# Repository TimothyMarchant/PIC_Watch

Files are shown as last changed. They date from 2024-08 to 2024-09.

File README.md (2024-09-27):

# PIC_Watch
A digital watch that tells the time and temperature.  It uses the PIC15225 microcontroller.  The screen is a 0.96 inch OLED (SSD1306).  
The purpose of this project was to make an actual embedded application because I was in need of a watch.  

Here are some pictures from start to finish.  

Breadboard prototype

prototype PCB

Finalized PCB with components soldered on
Without the screen (this is actually a different PCB than the other two pictures!)

Back side

With the screen


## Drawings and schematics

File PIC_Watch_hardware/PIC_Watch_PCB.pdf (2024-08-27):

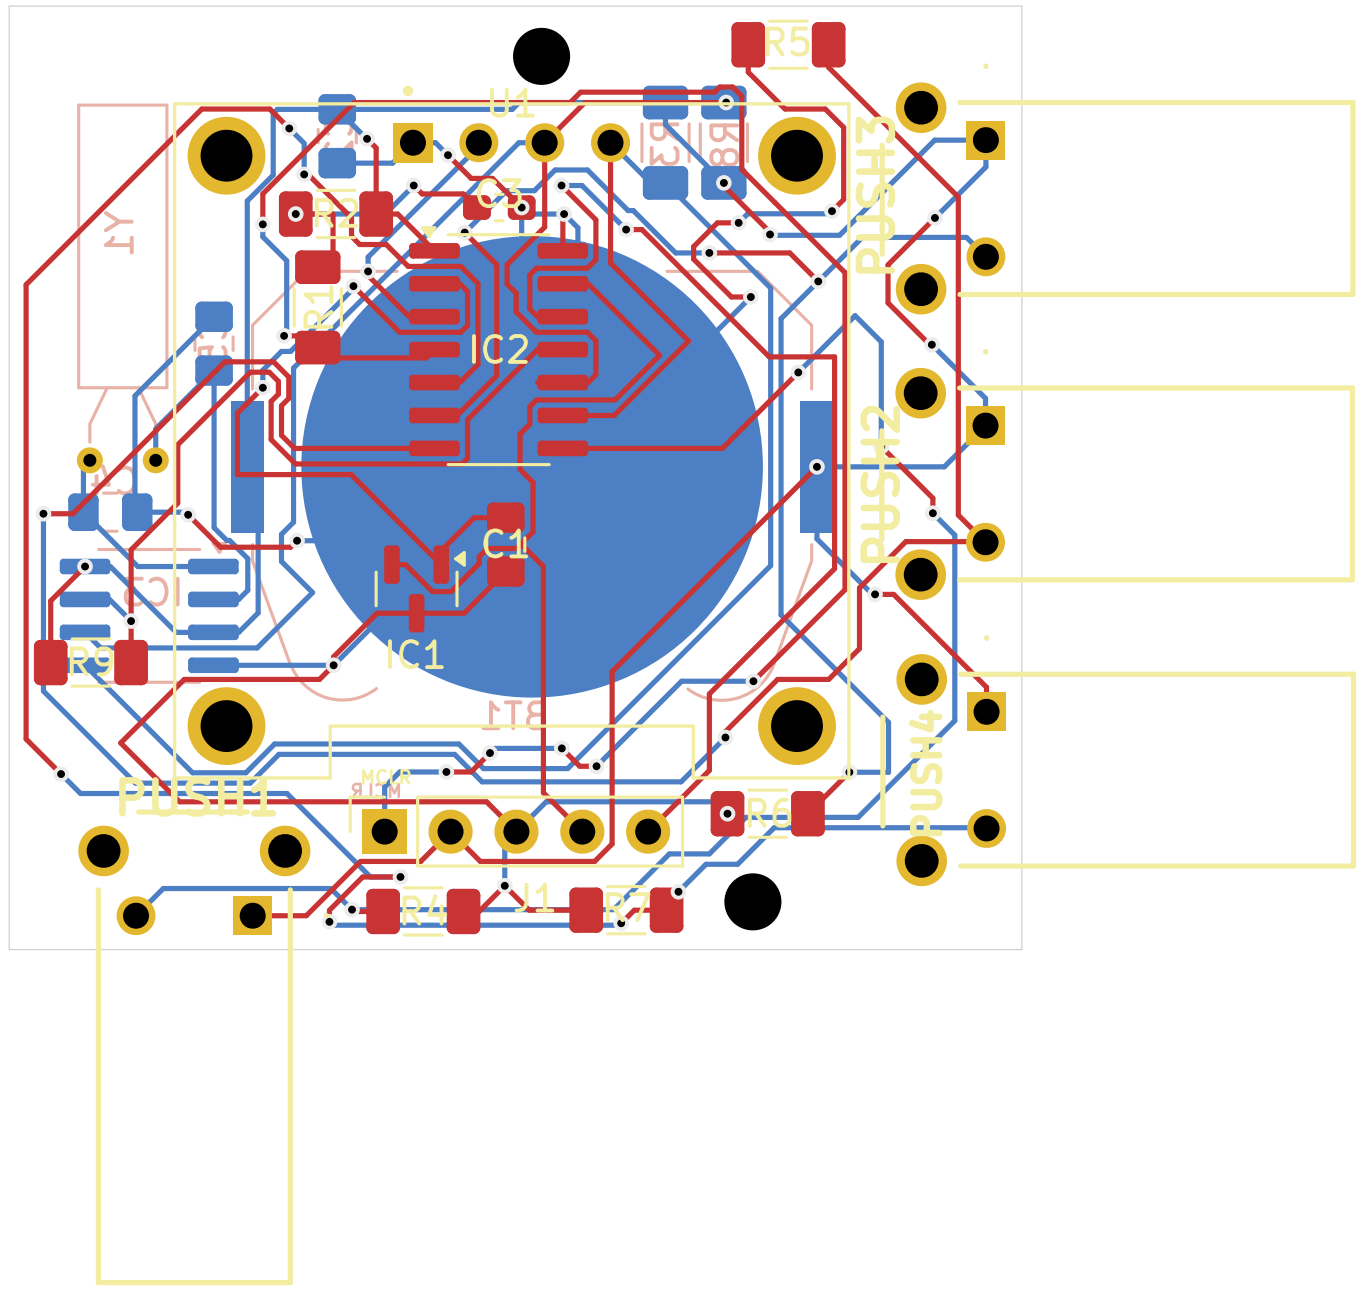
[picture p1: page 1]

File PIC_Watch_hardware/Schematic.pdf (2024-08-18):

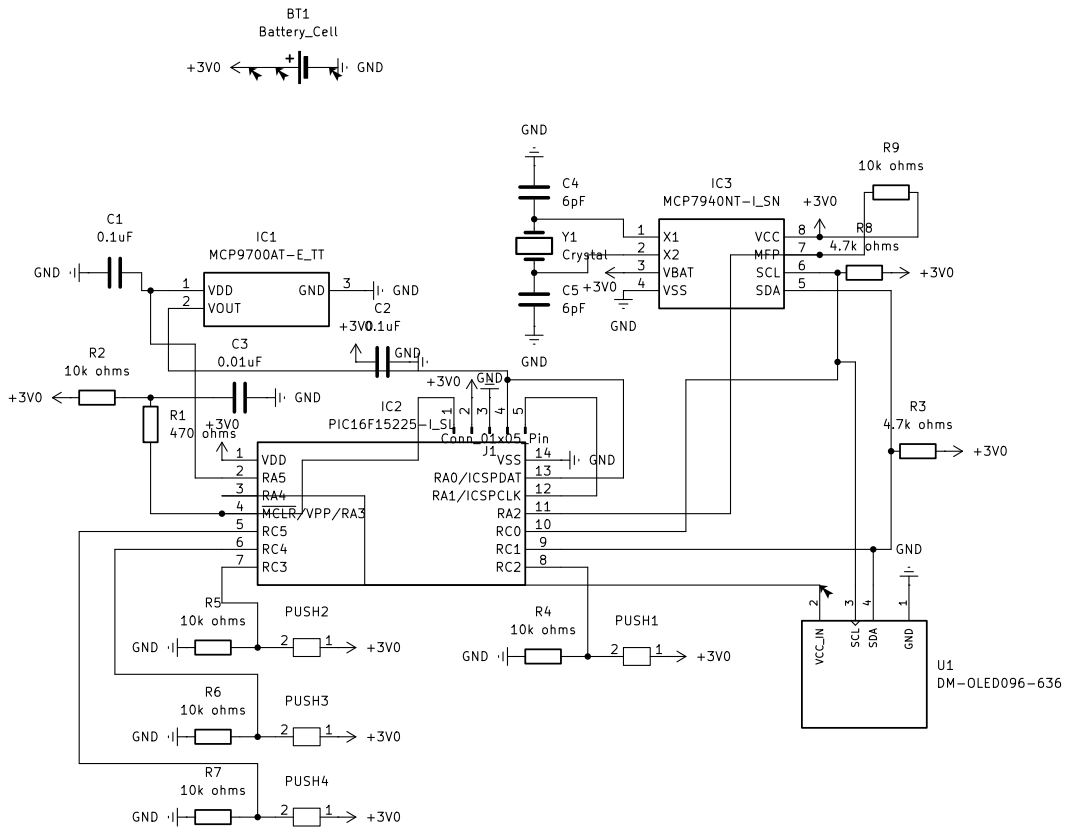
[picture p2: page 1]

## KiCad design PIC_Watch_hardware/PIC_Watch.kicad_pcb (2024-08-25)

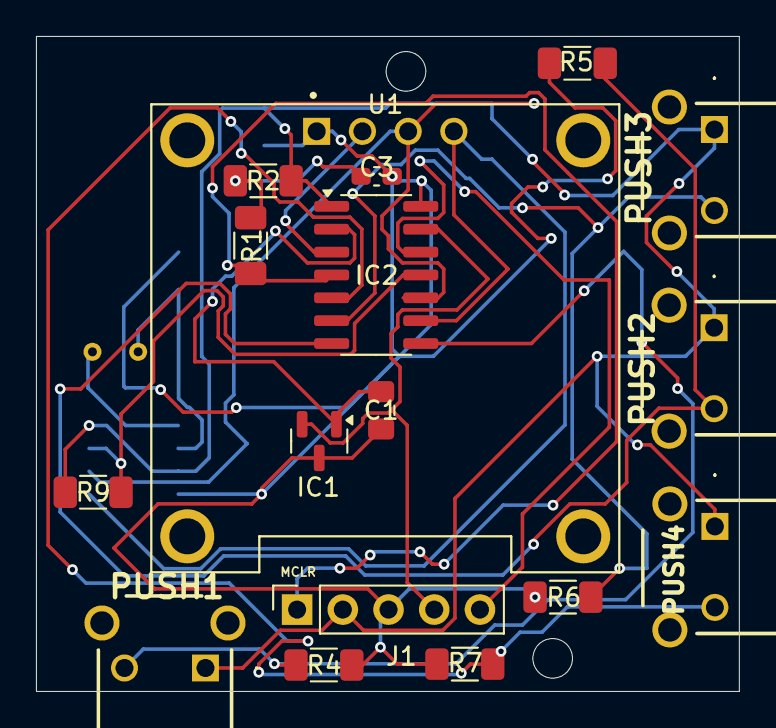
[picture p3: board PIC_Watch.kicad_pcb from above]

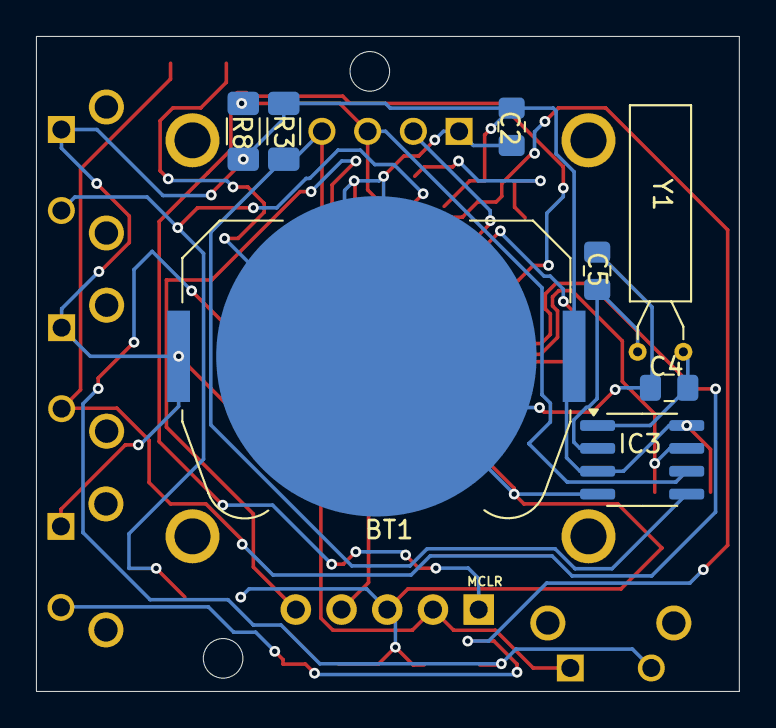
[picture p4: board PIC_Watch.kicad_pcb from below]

Board: 2 copper layers, 39.1 x 36.4 mm, 25 parts (8 on the bottom side), 17 nets.

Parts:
BT1: Battery_Cell; BatteryHolder_Keystone_3034_1x20mm
C1, C2: 0.1uF; C_0805_2012Metric_Pad1.18x1.45mm_HandSolder
C3: 0.01uF; C_0603_1608Metric_Pad1.08x0.95mm_HandSolder
C4, C5: 6pF; C_0805_2012Metric_Pad1.18x1.45mm_HandSolder
IC1: MCP9700AT-E_TT; SOT-23
IC2: PIC16F15225-I_SL; SOIC-14_3.9x8.7mm_P1.27mm
IC3: MCP7940NT-I_SN; SOIC-8_3.9x4.9mm_P1.27mm
J1: Conn_01x05_Pin; PinSocket_1x05_P2.54mm_Vertical
PUSH1, PUSH2, PUSH3, PUSH4: TS11674153BK160RAD
R1: 470 ohms; R_1206_3216Metric_Pad1.30x1.75mm_HandSolder
R2, R4, R5, R6, R7, R9: 10k ohms; R_1206_3216Metric_Pad1.30x1.75mm_HandSolder
R3, R8: 4.7k ohms; R_1206_3216Metric_Pad1.30x1.75mm_HandSolder
U1: DM-OLED096-636; MODULE_DM-OLED096-636
Y1: Crystal; Crystal_AT310_D3.0mm_L10.0mm_Horizontal

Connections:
+3V0: BT1.1 (+), C2.1, IC2.1 (VDD), IC3.3 (VBAT), IC3.8 (VCC), J1.2, PUSH1.1, PUSH2.1, PUSH3.1, PUSH4.1, R2.1, R3.2, R8.2, R9.2
GND: BT1.2 (-), C1.1, C2.2, C3.2, C4.2, C5.1, IC1.3 (GND), IC2.14 (VSS), IC3.4 (VSS), J1.3, R4.1, R5.1, R6.1, R7.1, U1.1 (GND)
unnamed: C3.1, R1.1, R2.2
unnamed: C1.2, IC1.1 (VDD), IC2.2 (RA5)
unnamed: IC1.2 (VOUT), IC2.13 (RA0/ICSPDAT), J1.4
unnamed: IC2.12 (RA1/ICSPCLK), J1.5
unnamed: IC2.11 (RA2), IC3.7 (MFP), R9.1
unnamed: IC2.3 (RA4), U1.2 (VCC_IN)
unnamed: IC2.10 (RC0), IC3.6 (SCL), R8.1, U1.3 (SCL)
unnamed: IC2.9 (RC1), IC3.5 (SDA), R3.1, U1.4 (SDA)
unnamed: IC2.8 (RC2), PUSH1.2, R4.2
unnamed: IC2.7 (RC3), PUSH2.2, R5.2
unnamed: IC2.6 (RC4), PUSH3.2, R6.2
unnamed: IC2.5 (RC5), PUSH4.2, R7.2
unnamed: IC2.4 (~MCLR/VPP/RA3), J1.1, R1.2
unnamed: C4.1, IC3.1 (X1), Y1.1
unnamed: C5.2, IC3.2 (X2), Y1.2

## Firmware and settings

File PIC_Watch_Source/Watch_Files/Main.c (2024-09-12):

#include "CONFIG.h"
#include "I2C_Drivers_PIC16F15225.h"
#include "SSD1306_Drivers.h"
#include "MCP9700_Drivers.h"
#include "MCP7940_Drivers.h"
/* This project uses the MCP7940N RTC, SSD1306, and the MCP9700 analog temperature sensor
 * This microcontroller was picked for several reasons
 * 1st, I had these in my house already and seemed to be big enough to do the job.
 * 2nd it's small enough for a <1.5 inch PCB (need it to be smaller than this more than likely; the PCB that is).
 * 
 */
#ifndef _XTAL_FREQ
#define _XTAL_FREQ 32000000
#endif
#define Button1 PORTCbits.RC2
#define Button2 PORTCbits.RC3
#define Button3 PORTCbits.RC4
#define Button4 PORTCbits.RC5
#define INTDATA 0xFF
#define PORTCButtons 0b00111100
#define OLED_POWER LATA4
void SendNumber(unsigned int);
void SendByte(unsigned char);
void HandleButton(unsigned char);
void EnableInterrupts(void);
void IncrementTimer1cnt(void);
unsigned char GetTimer1cnt(void);
unsigned int timer0cnt = 0;
unsigned char data = 0;
_Bool DeepSleep = 0;
_Bool IsPressed = 0;
_Bool NeedToUpdateTime=0;
void GotoSleep(void);
void DisplayTime(void);
void DisplayState(void);
void UpdateTimeArray(void);
void UpdateDateArray(void);
void UpdateYearArray(void);
void __interrupt() ISR(void) {
    //I2C recovery
    if (TMR1IF) {
        TMR1ON=0;
        IncrementTimer1cnt();
        TMR1IF=0;
        //timeout has clearly gone on too long restart the device after sending 9 clock pulses.
        if (GetTimer1cnt()==0xFF){
            ForceReset();
        }
        TMR1=0;
        TMR1ON=1;
    }
    //wakeup device.
    if (IOCCF>0) {
        //for debouncing
        __delay_ms(50);
        //get inputs from RC2-RC5 only.
        data = (PORTC & PORTCButtons)>>2;
        IOCCF = 0;
        IOCIF = 0;
        NeedToUpdateTime=0;
    }
    //alarm interrupt
    if (IOCAF>0){
        NeedToUpdateTime=1;
        //we need not update anything here, as the alarm pin will not change states until we modify the internal registers of the RTC.
        //The compiler gave a warning when we call such methods saying possible stack overflow.
        IOCIF=0;
        IOCAF=0;
    }
}
//this is for other files so that it can be changed elsewhere.
void GotoSleep(void){
    //
    DeepSleep=1;
    //do some other things.
}
void main(void) {
    TRISA = 0x00;
    LATA = 0x00;
    TRISA0=1;
    ANSELA=0x01;
    TRISA2=1;
    LATC = 0x00;
    //RC2-RC5 are all inputs.
    TRISC = 0xFF;
    ANSELC = 0x00;
    WPUC = 0x00;
    WPUA=0x00;
    OLED_POWER=1;
    Temp_Init(&LATA, 5);
    EnableInterrupts();
    I2C_Init();
    __delay_ms(50);
    init_OLED();
    MCP7940_Init();
    while (1) {
        //don't turn off the screen immediately wait some time then turn it off.
        HandleButton(data);
        if (DeepSleep) {
            DisplayTurnOff();
            //turn off alarm0 no interrupts are made in deep sleep.
            TurnOffInterrupt();
            //wait a little before just turning off the screen.
            __delay_ms(1);
            ClearAlarm0Interrupt();
            OLED_POWER=0;
            TMR1IE=0;
            data=0x00;
        }
        SLEEP();
        //We need this here instead of the ISR to avoid stack overflow.  The stack can only go 15 deep according to the datasheet (the compiler made a warning about it).
        
        //turn the screen back on.
        if (DeepSleep&&data!=0x00) {
            OLED_POWER=1;
            //wait some time before sending any commands.  the datasheet of the SSD1306 has the timing diagrams lasting a few microseconds, but I rather just wait longer
            //to avoid any problems.
            __delay_ms(25);
            init_OLED();
            //prevents the screen from having garbage shown.
            DisplayTurnOff();
            DeepSleep = 0;
        }
        if (NeedToUpdateTime){
            //update alarm time.
            updatealarm0();
            data=INTDATA;
            DeepSleep=0;
            NeedToUpdateTime=0;
        }
    }
}

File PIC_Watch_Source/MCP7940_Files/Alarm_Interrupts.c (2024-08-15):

//This file is special that it allows alarm0 to be configured to go off every minute to indicate that a new minute has past.
//It has no other function.  This makes it so that the microcontroller need not poll the RTC.
#include "I2C_Drivers_PIC16F15225.h"
#include "RTC_Addresses.h"
//starting values
//nonbinary time
unsigned char alarm0minutes[2]={0,0};
//these are the default control bytes for both alarms
//Alarm0 is set to go off on the matching of minutes.
#define Alarm0Control 0x10
//need this so that the methods below can call it.
void StartTransmission(unsigned char);
void ClearAlarm0Interrupt(void);
void updatealarm1(void);
//default options for control register
#define defaultcontrol 0x10
void updatealarmminutes(void){
    alarm0minutes[1]++;
    if (alarm0minutes[1]<10){
        return;
    }
    alarm0minutes[0]++;
    alarm0minutes[1]=0;
    if (alarm0minutes[0]==6){
        alarm0minutes[0]=0;
    }
}
void Init_Alarm0(void){
    StartTransmission(ALM0WKDay);
    I2C_Write(Alarm0Control);
    I2C_Restart();
    I2C_Write(RTC_Add);
    I2C_Write(CONTROL);
    I2C_Write(defaultcontrol);
    I2C_Stop();

}
void updatealarm0(void){
    //move memory pointer to minutes register
    StartTransmission(RTCMin);
    I2C_Restart();
    //read the minutes register.
    I2C_Write(RTC_Add|0x01);
    unsigned char temp=I2C_Read();
    NACK();
    //convert the binary time into something more useful.
    alarm0minutes[0]=(temp&0x70)>>4;
    alarm0minutes[1]=temp&0x0F;
    updatealarmminutes();
    unsigned char BINAlarmTime=(alarm0minutes[0]<<4)|alarm0minutes[1];
    I2C_Restart();
    I2C_Write(RTC_Add);
    I2C_Write(ALM0Min);
    I2C_Write(BINAlarmTime);
    //write to hours register to get to weekday register which contains the interrupt flag.
    //it's faster to write one byte here than restart the bus to get to the other register.
    I2C_Write(0x00);
    //update interrupt flag.
    I2C_Write(Alarm0Control);
    I2C_Stop();
}
void ClearAlarm0Interrupt(void){
    StartTransmission(ALM0WKDay);
    I2C_Write(Alarm0Control);
    I2C_Stop();
}
void TurnOffInterrupt(void){
    StartTransmission(CONTROL);
    I2C_Write(0);
    I2C_Stop();
}
void TurnOnInterrupt(void){
    StartTransmission(CONTROL);
    I2C_Write(defaultcontrol);
    I2C_Stop();
}

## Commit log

2024-08-03 Update Clock_Screens.c
    Uncommented a line. This prints the temperature. This was commented out because the prototyped PCB I had I guess I screwed up something when soldering the temperature sensor on and it was causing a short.
2024-08-03 Update Required_Files_MCP7940.c
    Fixed a bug if it were a leap year the month would appear incorrectly (If left alone we would have 32 months which is clearly nonsensical.)
    [Required_Files_MCP7940.c]
2024-08-05 Create Notes on I2C Recovery
2024-08-08 added more recovery files.
    Interrupt_Toggle will be updated as needed, it simply turns off all interrupts excluding timer 1.
2024-08-08 Update Required_I2C_Methods.c
    added timeout for I2C_Wait() and updated I2C_Stop() to fix a stuck bus that gets past I2C_Wait() (for some reason).
    [Required_I2C_Methods.c]
2024-08-08 added file for enabling interrupts at startup
2024-08-08 Update Main.c
    updated interrupt ISR to add support for I2C_Wait timeout.
    also rearranged a few things for startup.
2024-08-08 Update Notes on I2C Recovery
2024-08-08 Update Enable_Interrupts.c
    updated some comments on timer1.
2024-08-16 Update Main.c
    Added IO pin to control SSD1306 power supply. Limited testing has shown no problems.
    [Main.c]
2024-08-18 Update Clock_Screens.c
    Modified positioning of some things on the screen. Also added a check for February 29th. And made sure to clear the MCP7900 interrupt flag when in the settings to prevent it from being set where it is not needed.
2024-08-18 Update Screen_Logic.c
    Added handling for incorrect dates, so the user can't set it to dates like 00/39 or 12/00 (and other weird times). Also cleaned up unnecessary code and added some more comments. From all testing this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
2024-08-18 Added schematic
    This new folder will hold the PCB files soon enough. And any other CAD/model files.
2024-08-25 Added Kicad PCB design
    These are not the gerber files.
    [PIC_Watch.kicad_pcb]
2024-08-25 Create Battery Life notes
    These are the notes on power consumption.
2024-08-25 Update Battery Life notes
    updated notes to be more realistic to actual use case
2024-08-27 Added pdf of the PCB
2024-09-12 Create PCB_Notes_IMPORTANT
2024-09-12 Update Main.c fixes major problem
    As it turns out I forgot to reinitialize the screen after power off, so when I finally got the PCBs and soldered the PIC onto it and was testing it, I kept running into problems with the device resetting. Turns out I was not initializing the screen after restarting it.
    [Main.c]
2024-10-02 Update Battery Life notes
2024-10-13 Update Battery Life notes
    Updated notes on further testing
